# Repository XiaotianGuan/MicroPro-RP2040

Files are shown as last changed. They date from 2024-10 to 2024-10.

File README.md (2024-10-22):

**This repository contains the KiCad project, gerber, BOM and other associated files for MicroPro RP2040, a custom RP2040 based dev board compatible with Sparkfun ProMicro RP2040.**

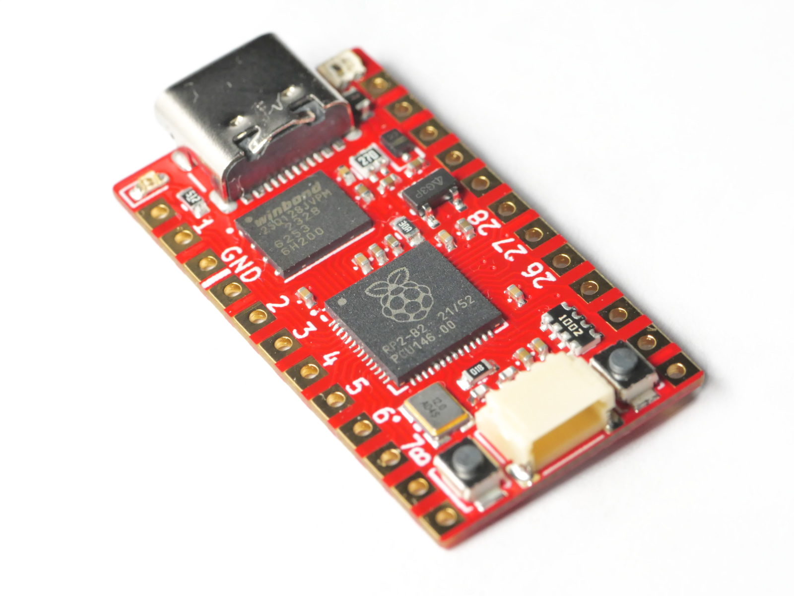
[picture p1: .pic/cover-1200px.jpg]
[Cover]


The RP2040 is a great microcontroller, plenty powerful, well documented, and cheap. However, its on board ADC kinda sucked. I have another project which incorporates a Sparkfun ProMicro RP2040 board that uses the ADC, and I wish I can get more out of it. 

I really liked the ProMicro form factor. It's relatively small, has plenty of flash and enough GPIO. I also thought it might provide an upgrade path, which turned out to be correct(though that's long before RP2350 was announced). So I decided to design a custom board with a better stand-alone ADC that's drop-in compatible. Meaning the pinout has to stay the same, and the input to the ADC has to be muxed.

The analog pins of the RP2040 (GP26-GP29) are directly wired to the board's pads. While those four pads are also connected to *tmux1204*, a 4:1 mux, whose drain is connected to the *ads7042*, a 1-MSPS, 12-bit, single channel ADC.

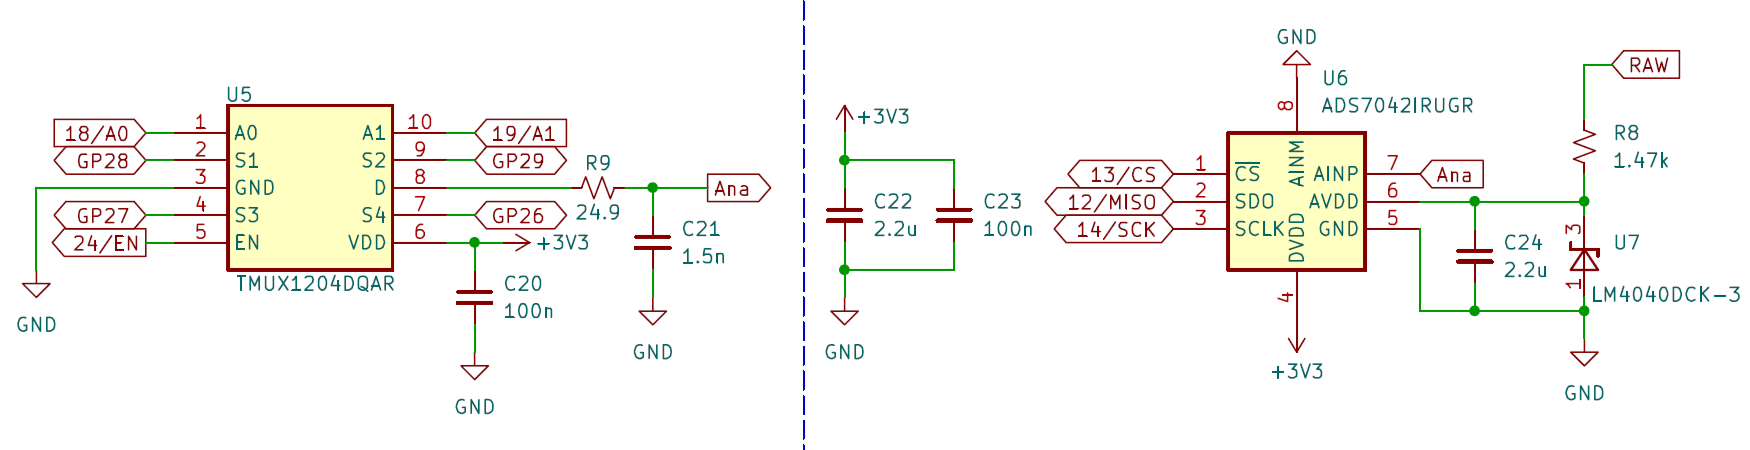
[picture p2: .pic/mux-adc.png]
[mux-adc]


By default, this board should behave no differently than the original. To use the stand-alone ADC, you need to first configure the multiplexer to connect the right pin to the ADC and set the corresponding RP2040 pin to input. This provides better ADC performance, and in theory can achieve 1M sampling rate, double what the on board ADC can do. (Not tested yet.) Though the input filter may need to be redesigned for such high sampling rate.

**Differences**

Though this board is designed to be compatible with Sparkfun ProMicro RP2040, there are a number of differences. First, most significantly, this is a double sided board. Therefore by default it does not have castellated pads, thought a castellated footprint is provided. Second, the push buttons are not the same part used on the Sparkfun board. They're smaller and not as tall, but are at the same position. Third, the pull-up resistance for the qwiic connector is 10k instead of 2.2k, which may limit the maximum I2C clockrate.

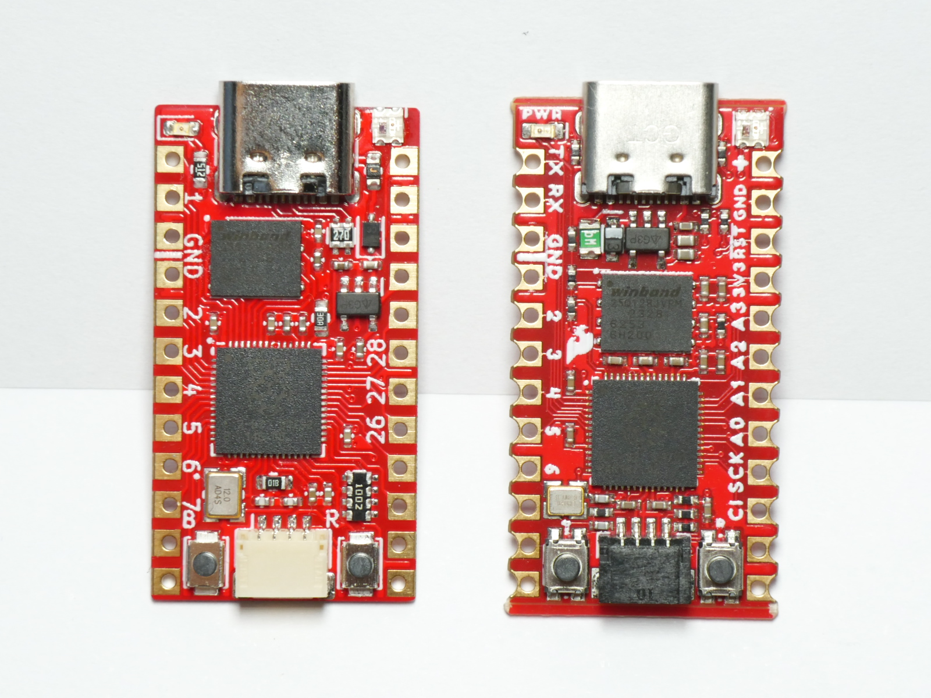
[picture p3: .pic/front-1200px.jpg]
[front]

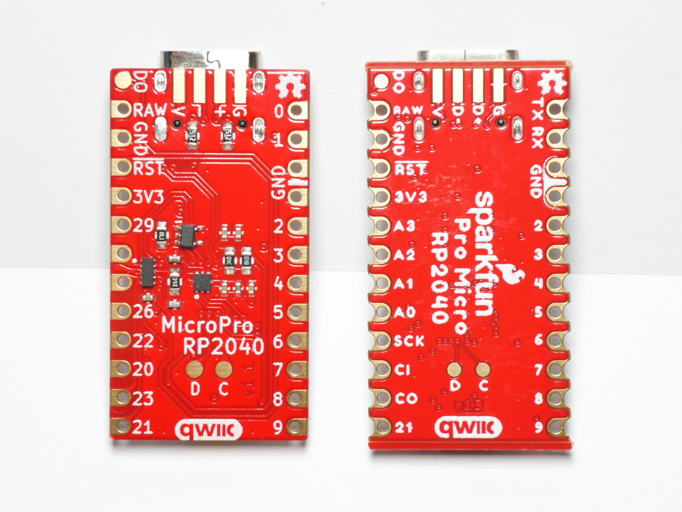
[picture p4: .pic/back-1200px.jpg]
[back]


Finally, regarding fabrication. Unlike the Sparkfun board, which uses thin traces and tiny vias. This board is designed for JLCPCB's cheapest 4 layer process. All vias are 0.5mm with 0.3mm drill. USB differential pair is designed for *JLC04081H-3313*, JLC's free tier of impedance controlled boards. Though at 12Mbps, it likely would not have mattered anyway.

By default, this board does not have castellated pads. If your application requires it, replace the footprint for J3 with *12x2 castellated* in the project footprint library. No other modification necessary. Note this will likely incur additional cost for fabrication.

---

# License

The work is released under CC BY-SA 4.0 license.

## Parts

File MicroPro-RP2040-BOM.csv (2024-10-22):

Reference | Value | Footprint | Qty | Manufacturer_Part_Number | Comments
C1,C2 | 15p | Capacitor_SMD:C_0402_1005Metric | 2 |  | C0G dielectric
C3,C4,C5,C6,C7,C8,C9,C11,C12,C18,C20,C23 | 100n | Capacitor_SMD:C_0402_1005Metric | 12
C10,C13,C14,C15,C16,C17,C22,C24 | 2.2u | Capacitor_SMD:C_0402_1005Metric | 8
C21 | 1.5n | Capacitor_SMD:C_0402_1005Metric | 1 |  | C0G dielectric
D1 | PMEG2005EJ | Diode_SMD:D_SOD-323F | 1 | PMEG2005EJ-QX
D2 | RED | LED_SMD:LED_0603_1608Metric | 1
D3 | WS2812B-2020 | LED_SMD:LED_WS2812B-2020_PLCC4_2.0x2.0mm | 1
F1 | 6V 0.5A | Fuse:Fuse_0603_1608Metric | 1 | SMD0603B050TF
G1 | qwiic_Logo |  | 1
J1 | USB_C_Receptacle_USB2.0_16P | Connector_USB:USB_C_Receptacle_GCT_USB4105-xx-A_16P_TopMnt_Horizontal | 1
J2 | Qwiic | Connector_JST:JST_SH_SM04B-SRSS-TB_1x04-1MP_P1.00mm_Horizontal | 1 | SM04B-SRSS-TB(LF)(SN)(P)
J3 | Conn_02x12_Counter_Clockwise | MicroPro:12x2 through hole | 1
J4 | Conn_01x04 | MicroPro:USB pad | 1
R1 | 200 | Resistor_SMD:R_0603_1608Metric | 1
R2,R4 | 1k | Resistor_SMD:R_0603_1608Metric | 2
R3,R6,R7 | 5.1k | Resistor_SMD:R_0603_1608Metric | 3
R5 | 10k | Resistor_SMD:R_0603_1608Metric | 1
R8 | 1.47k | Resistor_SMD:R_0603_1608Metric | 1
R9 | 24.9 | Resistor_SMD:R_0603_1608Metric | 1
RN1 | EXB-V4V270JV | MicroPro:EXBV4V | 1 | EXB-V4V270JV
RN2 | CAT16-1002F4LF | MicroPro:CAT16104J4LF | 1 | CAT16-1002F4LF
SW1 | Boot | Button_Switch_SMD:SW_SPST_B3U-1000P | 1
SW2 | Reset | Button_Switch_SMD:SW_SPST_B3U-1000P | 1
TP1,TP2,TP3 | TestPoint_Small | TestPoint:TestPoint_Pad_D1.5mm | 3
U1 | RP2040 | Package_DFN_QFN:QFN-56-1EP_7x7mm_P0.4mm_EP3.2x3.2mm | 1
U2 | AP2112K-3.3 | Package_TO_SOT_SMD:SOT-23-5 | 1 | AP2112K-3.3TRG1
U3 | W25Q128JV | Package_SON:WSON-8-1EP_6x5mm_P1.27mm_EP3.4x4.3mm | 1 | W25Q128JVPIM
U5 | TMUX1204DQAR | MicroPro:TMUX1204DQAR | 1 | TMUX1204DQAR
U6 | ADS7042IRUGR | MicroPro:ADS7056IRUGR | 1 | ADS7042IRUGR
U7 | LM4040DCK-3 | Package_TO_SOT_SMD:SOT-353_SC-70-5 | 1 | LM4040A30IDCKR
Y1 | ABM8-272-T3 | MicroPro:ABM8272T3 | 1 | ABM8-272-T3

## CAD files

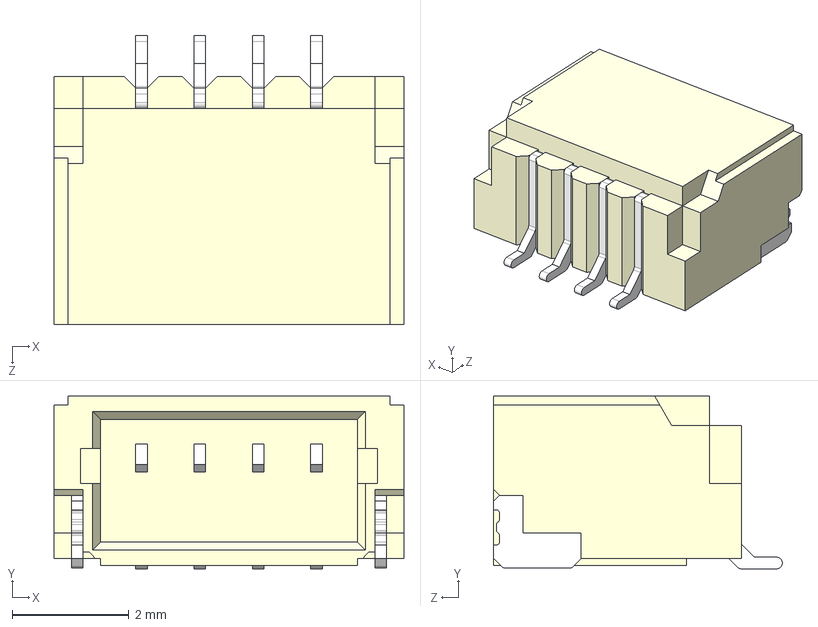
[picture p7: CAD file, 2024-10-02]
MicroPro_3D/SM04B-SRSS-TB_LF__DN__P_.stp
6.00 x 2.96 x 4.95 mm

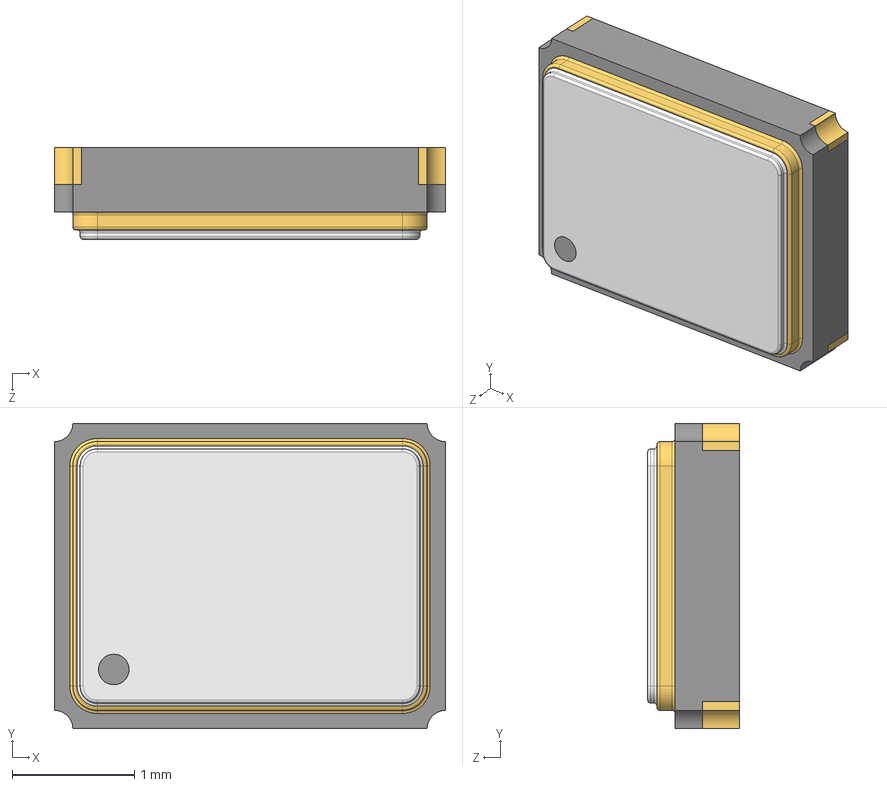
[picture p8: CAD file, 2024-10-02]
MicroPro_3D/ABM8-272-T3.stp
3.20 x 2.50 x 0.75 mm

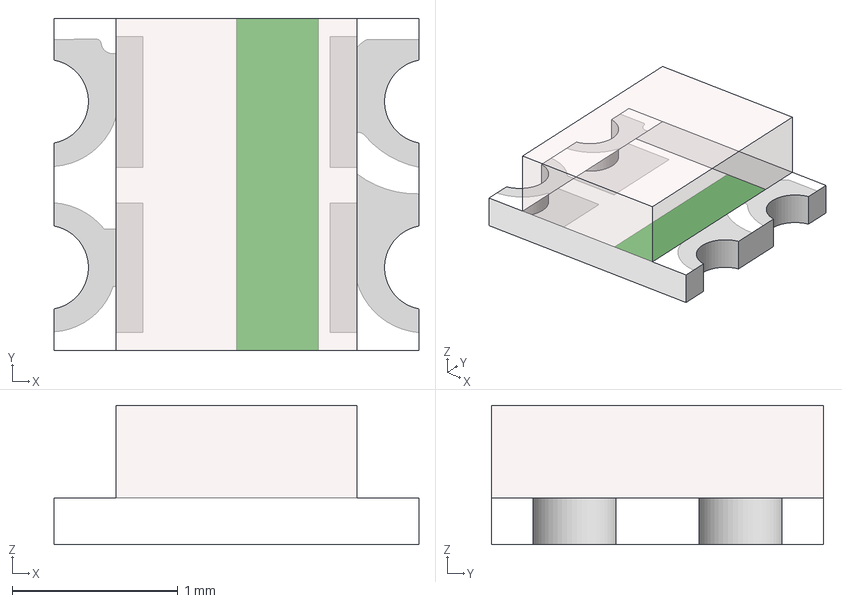
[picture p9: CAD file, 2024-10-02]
MicroPro_3D/ws2812b.stp
2.20 x 2.00 x 0.84 mm

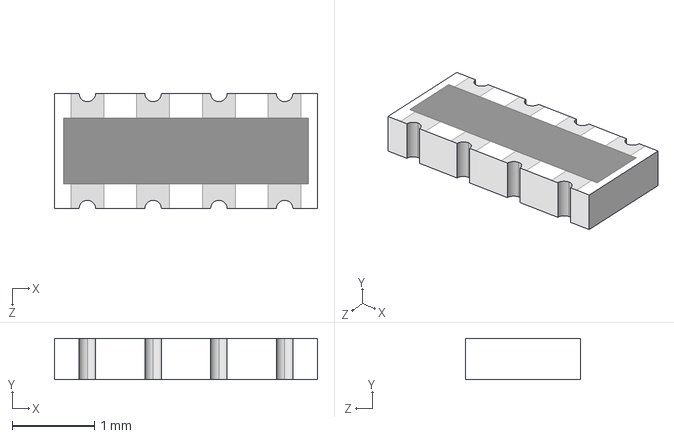
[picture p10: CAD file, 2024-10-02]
MicroPro_3D/CAT16-1003F4LF.stp
3.20 x 0.5 x 1.40 mm

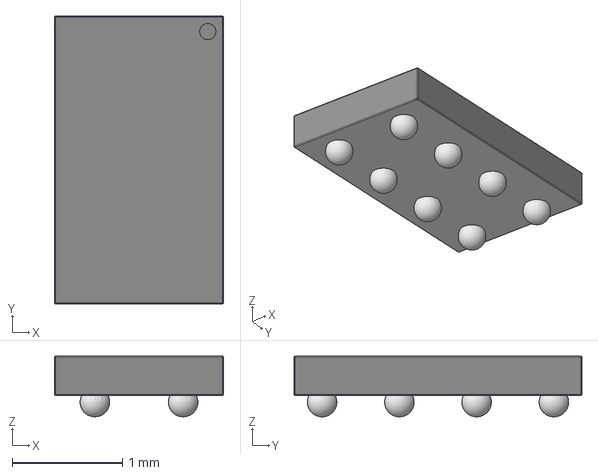
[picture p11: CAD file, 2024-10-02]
MicroPro_3D/M95P32IXCSTEF.stp
1.53 x 2.61 x 0.549 mm

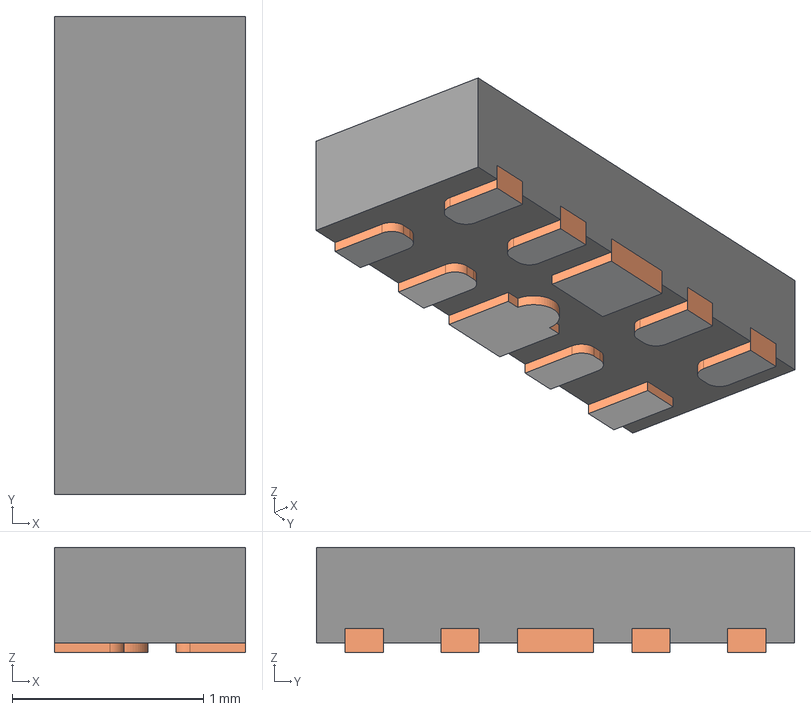
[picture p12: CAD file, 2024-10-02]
MicroPro_3D/TMUX1204DQAR.stp
1.00 x 2.50 x 0.55 mm
BODY-SON
FRAME-DQA0010A
PIN1-ID

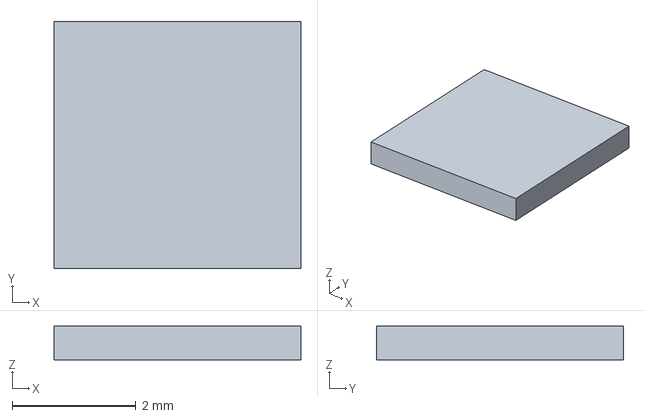
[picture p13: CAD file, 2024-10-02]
MicroPro_3D/M95P32IXMGTE.step
4.00 x 4.00 x 0.55 mm

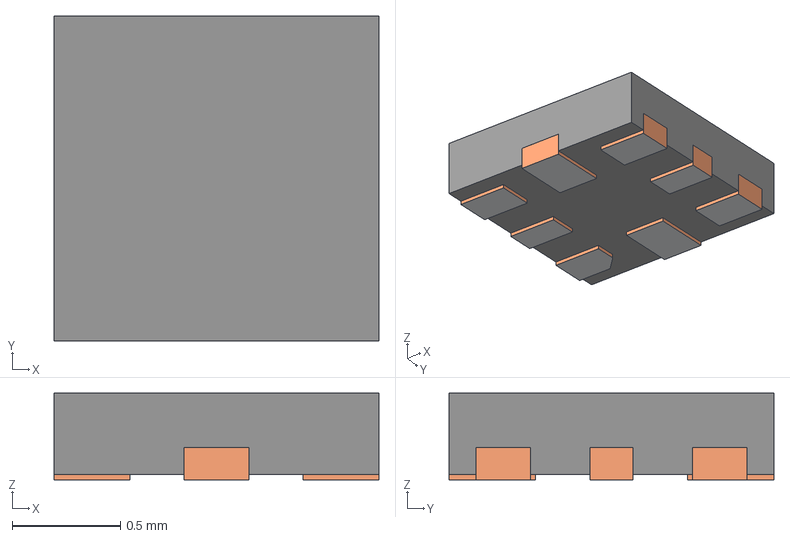
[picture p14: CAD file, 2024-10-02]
MicroPro_3D/ADS7044IRUGR.stp
1.50 x 1.50 x 0.4 mm
FRAME-RUG0008A
BODY-QFN
PIN1-ID

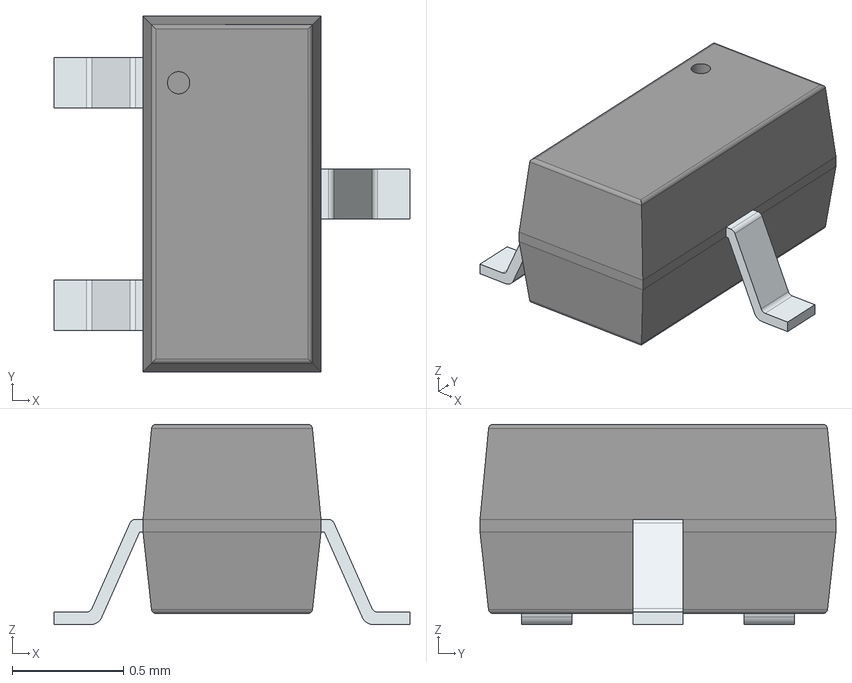
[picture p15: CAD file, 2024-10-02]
MicroPro_3D/D5V0L2B3T-7.stp
1.60 x 1.60 x 0.9 mm
PinsArrayL
FilletPinR

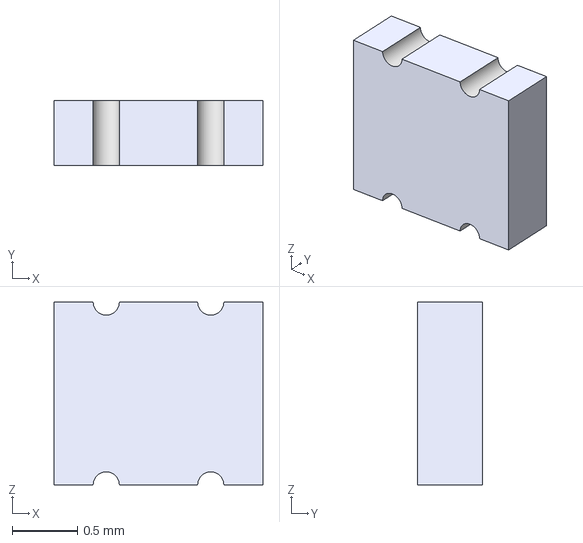
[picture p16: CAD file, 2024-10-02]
MicroPro_3D/EXBV4V.step
1.60 x 0.5 x 1.40 mm

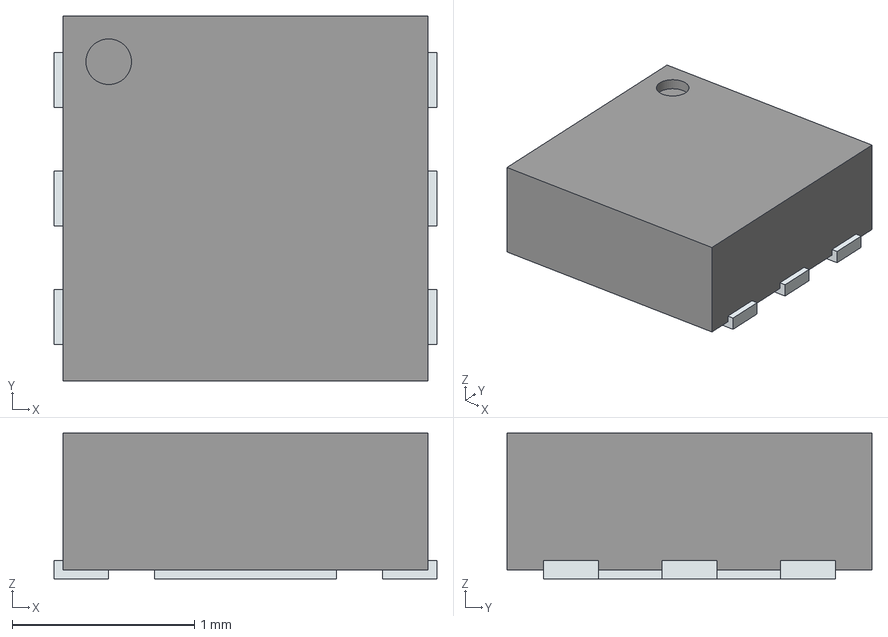
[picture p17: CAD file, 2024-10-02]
MicroPro_3D/TPS73533DRVT.stp
2.10 x 2.00 x 0.8 mm
ThermalPin
PinsArrayLR

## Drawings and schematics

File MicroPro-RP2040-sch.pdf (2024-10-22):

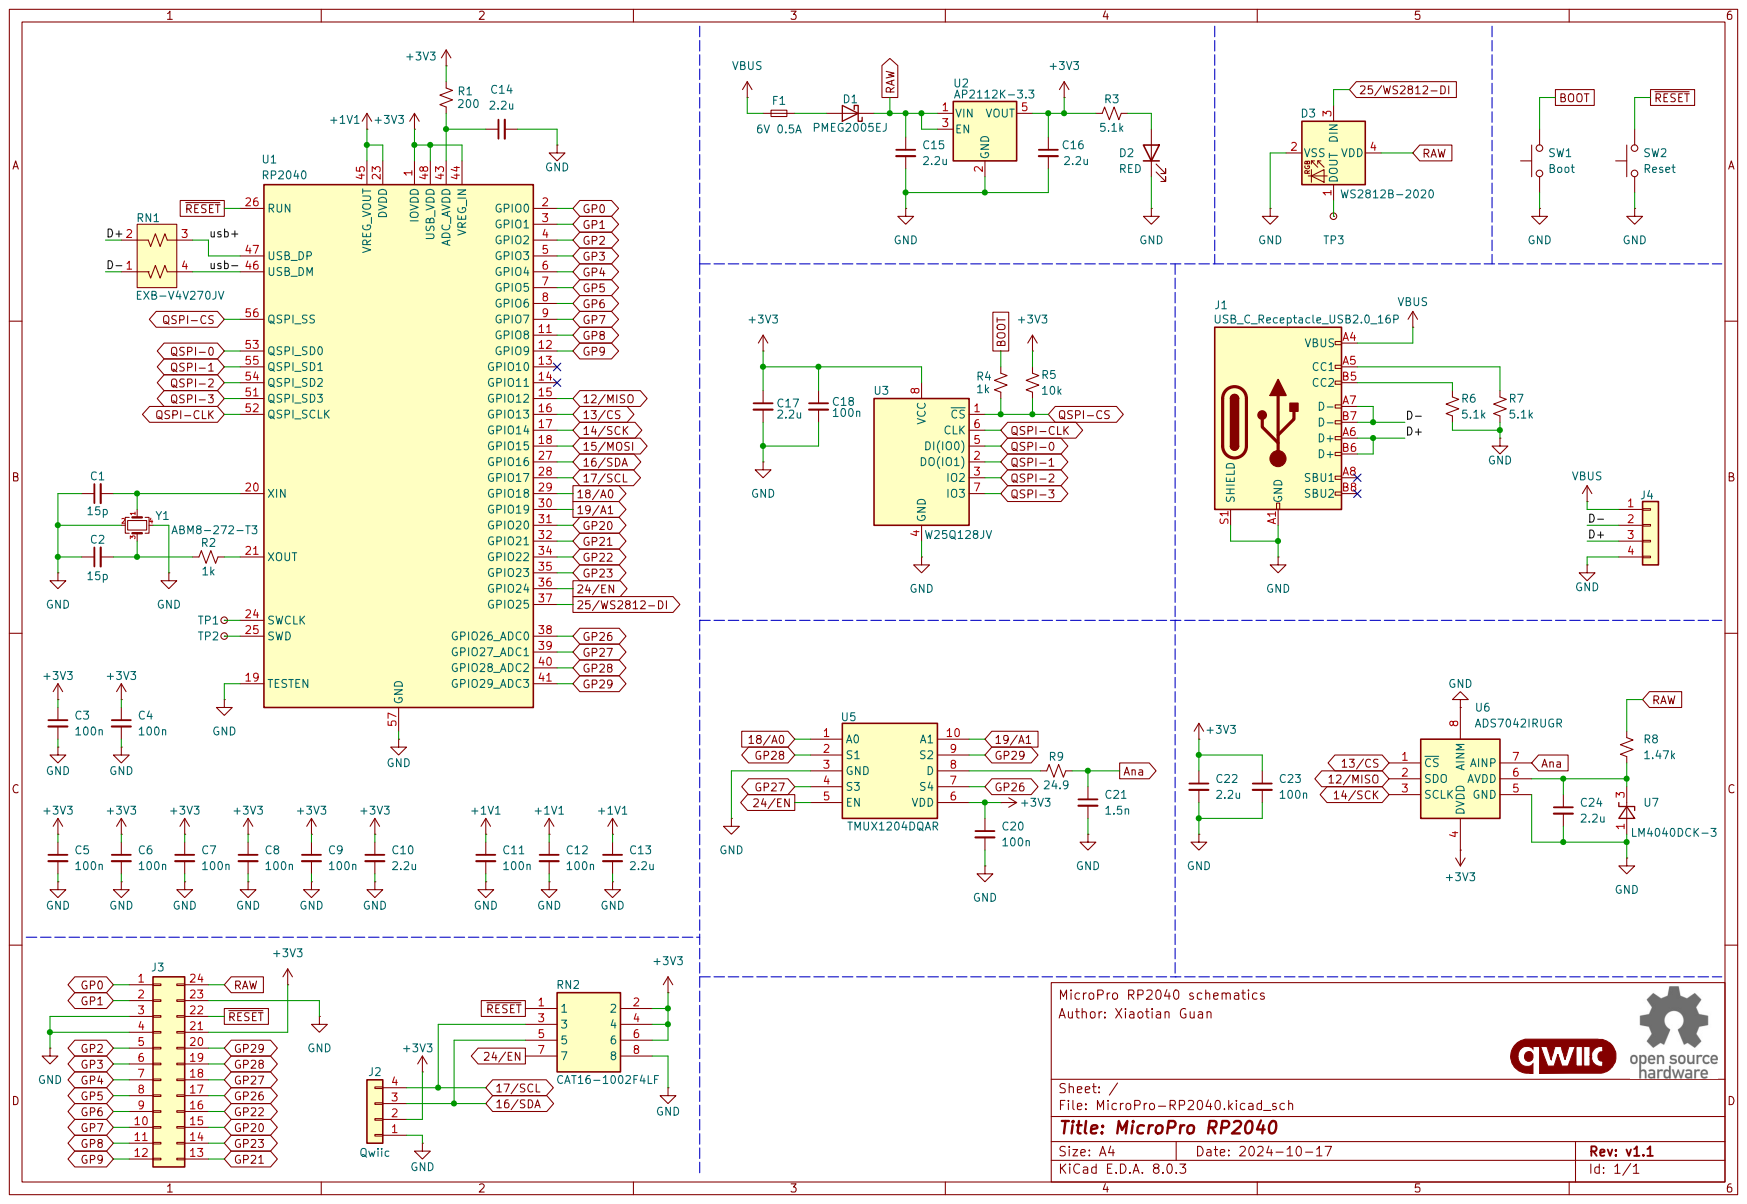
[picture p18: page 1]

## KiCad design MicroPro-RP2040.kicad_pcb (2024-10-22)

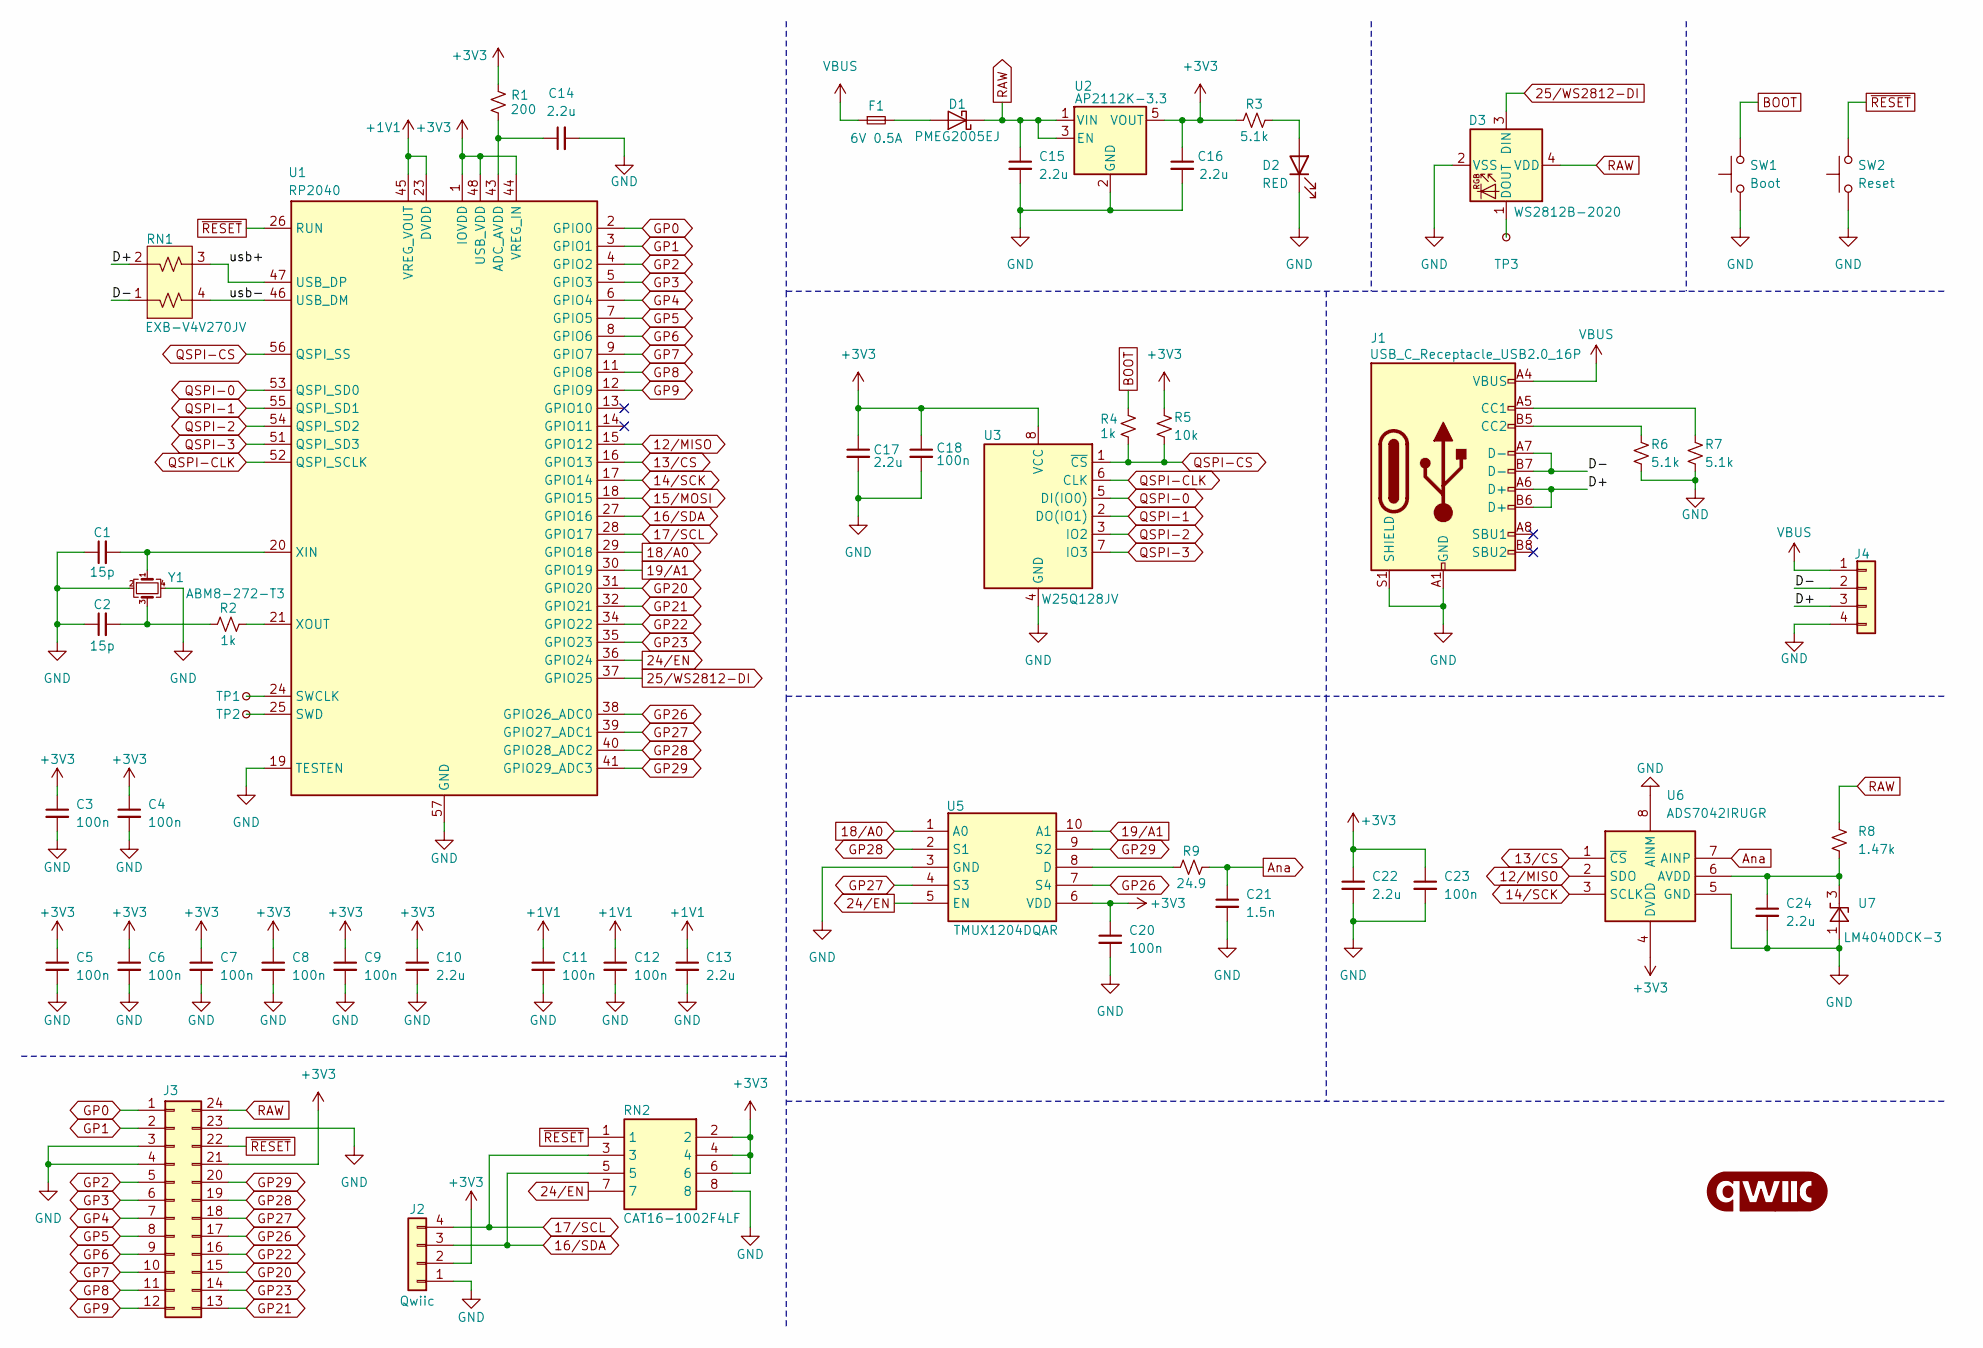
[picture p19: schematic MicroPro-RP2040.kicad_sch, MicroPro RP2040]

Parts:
C1, C2: 15p; C_0402_1005Metric
C3, C4, C5, C6, C7, C8, C9, C11, C12, C18, C20, C23: 100n; C_0402_1005Metric
C10, C13, C14, C15, C16, C17, C22, C24: 2.2u; C_0402_1005Metric
C21: 1.5n; C_0402_1005Metric
D1: PMEG2005EJ; D_SOD-323F; Manufacturer_Part_Number PMEG2005EJ-QX
D2: RED; LED_0603_1608Metric
D3: WS2812B-2020; LED_WS2812B-2020_PLCC4_2.0x2.0mm
F1: 6V 0.5A; Fuse_0603_1608Metric; Manufacturer_Part_Number SMD0603B050TF
G1: qwiic_Logo
J1: USB_C_Receptacle_USB2.0_16P; USB_C_Receptacle_GCT_USB4105-xx-A_16P_TopMnt_Horizontal
J2: Qwiic; JST_SH_SM04B-SRSS-TB_1x04-1MP_P1.00mm_Horizontal; Manufacturer_Part_Number SM04B-SRSS-TB(LF)(SN)(P)
J3: Conn_02x12_Counter_Clockwise; 12x2 through hole
J4: Conn_01x04; USB pad
R1: 200; R_0603_1608Metric
R2, R4: 1k; R_0603_1608Metric
R3, R6, R7: 5.1k; R_0603_1608Metric
R5: 10k; R_0603_1608Metric
R8: 1.47k; R_0603_1608Metric
R9: 24.9; R_0603_1608Metric
RN1: EXB-V4V270JV; EXBV4V; Manufacturer_Part_Number EXB-V4V270JV
RN2: CAT16-1002F4LF; CAT16104J4LF; Mouser Part Number 652-CAT16-1003F4LF
SW1: Boot; SW_SPST_B3U-1000P
SW2: Reset; SW_SPST_B3U-1000P
TP1, TP2, TP3: TestPoint_Small; TestPoint_Pad_D1.5mm
U1: RP2040; QFN-56-1EP_7x7mm_P0.4mm_EP3.2x3.2mm
U2: AP2112K-3.3; SOT-23-5; Manufacturer_Part_Number AP2112K-3.3TRG1
U3: W25Q128JV; WSON-8-1EP_6x5mm_P1.27mm_EP3.4x4.3mm; Manufacturer_Part_Number W25Q128JVPIM
U5: TMUX1204DQAR; Mouser Part Number 595-TMUX1204DQAR
U6: ADS7042IRUGR; ADS7056IRUGR; Manufacturer_Part_Number ADS7042IRUGR
U7: LM4040DCK-3; SOT-353_SC-70-5; Manufacturer_Part_Number LM4040A30IDCKR
Y1: ABM8-272-T3; ABM8272T3; Manufacturer_Part_Number ABM8-272-T3

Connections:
12/MISO: U1.15 (GPIO12), U6.2 (SDO)
13/CS: U1.16 (GPIO13), U6.1 (~CS)
14/SCK: U1.17 (GPIO14), U6.3 (SCLK)
15/MOSI: U1.18 (GPIO15)
16/SDA: J2.3, RN2.5, U1.27 (GPIO16)
17/SCL: J2.4, RN2.3, U1.28 (GPIO17)
18/A0: U1.29 (GPIO18), U5.1 (A0)
19/A1: U1.30 (GPIO19), U5.10 (A1)
24/EN: RN2.7, U1.36 (GPIO24), U5.5 (EN)
25/WS2812-DI: D3.3 (DIN), U1.37 (GPIO25)
+1V1: C11.1, C12.1, C13.1, U1.23 (DVDD), U1.45 (VREG_VOUT), U1.50 (DVDD)
+3V3: C3.1, C4.1, C5.1, C6.1, C7.1, C8.1, C9.1, C10.1, C16.1, C17.1, C18.1, C20.1, C22.1, C23.1, J2.2, J3.21, R1.1, R3.1, R5.1, RN2.2, RN2.4, RN2.6, U1.1 (IOVDD), U1.10 (IOVDD), U1.22 (IOVDD), U1.33 (IOVDD), U1.42 (IOVDD), U1.44 (VREG_IN), U1.48 (USB_VDD), U1.49 (IOVDD), U2.5 (VOUT), U3.8 (VCC), U5.6 (VDD), U6.4 (DVDD)
/D+: J1.A6 (D+), J1.B6 (D+), J4.3, RN1.2
/D-: J1.A7 (D-), J1.B7 (D-), J4.2, RN1.1
/usb+: RN1.3, U1.47 (USB_DP)
/usb-: RN1.4, U1.46 (USB_DM)
Ana: C21.1, R9.2, U6.7 (AINP)
BOOT: R4.1, SW1.2
GND: C1.1, C2.1, C3.2, C4.2, C5.2, C6.2, C7.2, C8.2, C9.2, C10.2, C11.2, C12.2, C13.2, C14.2, C15.2, C16.2, C17.2, C18.2, C20.2, C21.2, C22.2, C23.2, C24.2, D2.1 (K), D3.2 (VSS), J1.A1 (GND), J1.A12 (GND), J1.B1 (GND), J1.B12 (GND), J1.S1 (SHIELD), J2.1, J3.3, J3.4, J3.23, J4.4, R6.2, R7.2, RN2.8, SW1.1, SW2.1, U1.19 (TESTEN), U1.57 (GND), U2.2 (GND), U3.4 (GND), U3.9, U5.3 (GND), U6.5 (GND), U6.8 (AINM), U7.1 (A), U7.5 (NC), Y1.2, Y1.4
GP0: J3.1, U1.2 (GPIO0)
GP1: J3.2, U1.3 (GPIO1)
GP2: J3.5, U1.4 (GPIO2)
GP3: J3.6, U1.5 (GPIO3)
GP4: J3.7, U1.6 (GPIO4)
GP5: J3.8, U1.7 (GPIO5)
GP6: J3.9, U1.8 (GPIO6)
GP7: J3.10, U1.9 (GPIO7)
GP8: J3.11, U1.11 (GPIO8)
GP9: J3.12, U1.12 (GPIO9)
GP20: J3.15, U1.31 (GPIO20)
GP21: J3.13, U1.32 (GPIO21)
GP22: J3.16, U1.34 (GPIO22)
GP23: J3.14, U1.35 (GPIO23)
GP26: J3.17, U1.38 (GPIO26_ADC0), U5.7 (S4)
GP27: J3.18, U1.39 (GPIO27_ADC1), U5.4 (S3)
GP28: J3.19, U1.40 (GPIO28_ADC2), U5.2 (S1)
GP29: J3.20, U1.41 (GPIO29_ADC3), U5.9 (S2)
unnamed: C2.2, R2.1, Y1.3
unnamed: D1.2 (A), F1.2
unnamed: D2.2 (A), R3.2
unnamed: D3.1 (DOUT), TP3.1
unnamed: J1.A5 (CC1), R7.1
unnamed: J1.B5 (CC2), R6.1
unnamed: C14.1, R1.2, U1.43 (ADC_AVDD)
unnamed: TP1.1, U1.24 (SWCLK)
unnamed: TP2.1, U1.25 (SWD)
unnamed: C1.2, U1.20 (XIN), Y1.1
unnamed: R2.2, U1.21 (XOUT)
unnamed: R9.1, U5.8 (D)
unnamed: C24.1, R8.2, U6.6 (AVDD), U7.3 (K)
QSPI-0: U1.53 (QSPI_SD0), U3.5 (DI(IO0))
QSPI-1: U1.55 (QSPI_SD1), U3.2 (DO(IO1))
QSPI-2: U1.54 (QSPI_SD2), U3.3 (IO2)
QSPI-3: U1.51 (QSPI_SD3), U3.7 (IO3)
QSPI-CLK: U1.52 (QSPI_SCLK), U3.6 (CLK)
QSPI-CS: R4.2, R5.2, U1.56 (QSPI_SS), U3.1 (~CS)
RAW: C15.1, D1.1 (K), D3.4 (VDD), J3.24, R8.1, U2.1 (VIN), U2.3 (EN)
VBUS: F1.1, J1.A4 (VBUS), J1.A9 (VBUS), J1.B4 (VBUS), J1.B9 (VBUS), J4.1
~RESET: J3.22, RN2.1, SW2.2, U1.26 (RUN)

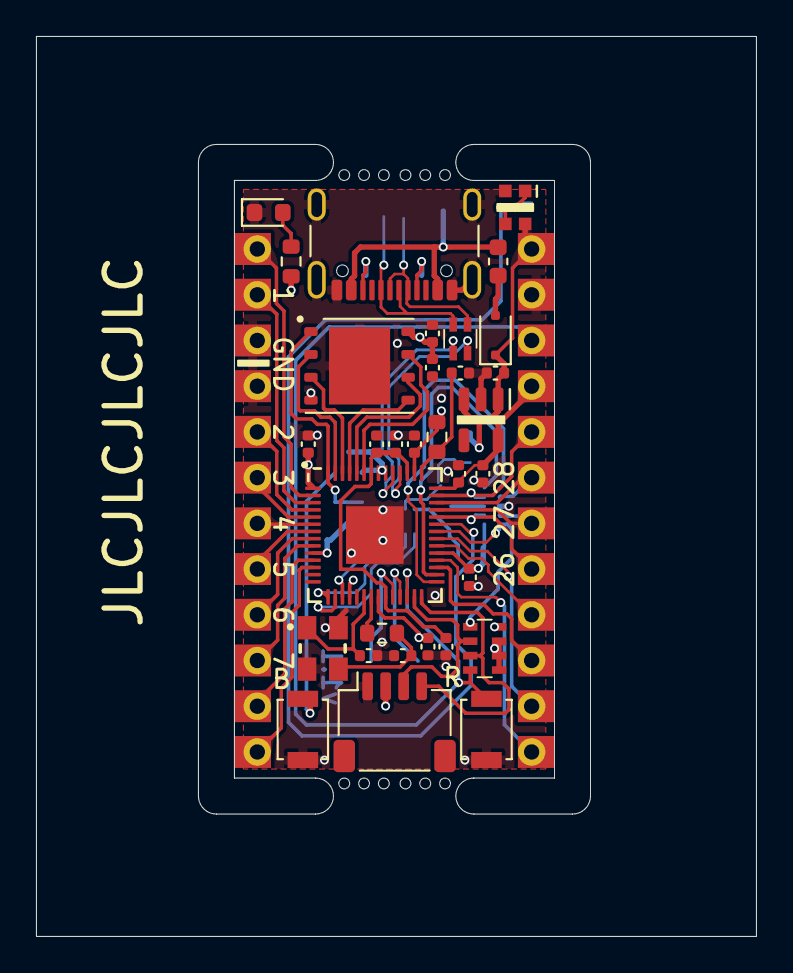
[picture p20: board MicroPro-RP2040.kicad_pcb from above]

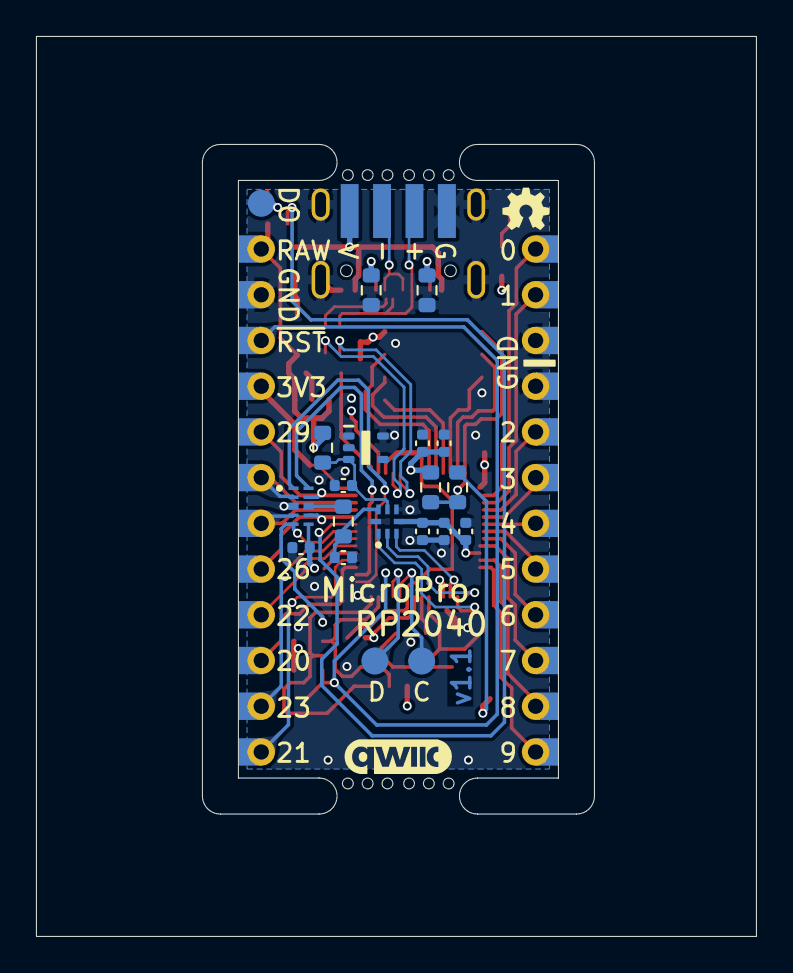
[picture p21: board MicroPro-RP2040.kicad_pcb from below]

Board: 4 copper layers, 40.0 x 50.0 mm, 54 parts (21 on the bottom side), 58 nets.

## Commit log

2024-10-02 v0.1 initial commit
    [ABM8-272-T3.stp, ADS7044IRUGR.stp, CAT16-1003F4LF.stp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]
2024-10-02 removed no longer used sheet
    [carrier_board.kicad_sch]
2024-10-03 completed schematics, generated BOM
    [MicroPro-RP2040-BOM.csv, MicroPro-RP2040.kicad_sch]
2024-10-03 fixed typo in schematics
2024-10-04 v1.0 board
    [MicroPro-RP2040.kicad_pcb]
2024-10-04 cleaned up schematics
    [MicroPro-RP2040.kicad_sch]
2024-10-04 optimized via position
    [MicroPro-RP2040.kicad_pcb]
2024-10-05 fixed miswiring in schematics, v1.1 board
    [MicroPro-RP2040.kicad_pcb, MicroPro-RP2040.kicad_sch]
2024-10-22 generated gerber, added license, readme
    [MicroPro-RP2040-BOM.csv, MicroPro-RP2040.kicad_pcb, MicroPro-RP2040.kicad_sch]
